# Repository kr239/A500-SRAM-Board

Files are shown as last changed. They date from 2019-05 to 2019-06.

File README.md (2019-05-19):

# A500-SRAM-Board

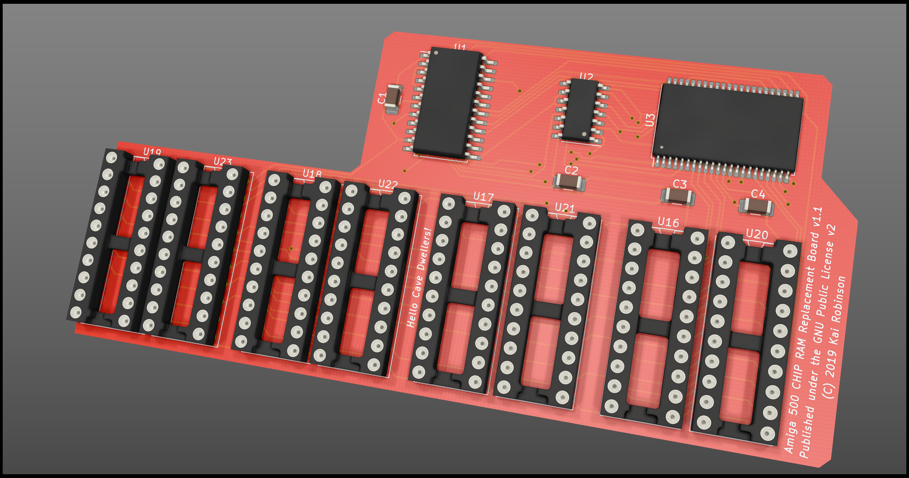
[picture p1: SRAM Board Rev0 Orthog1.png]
A500 SRAM Replacement Board


As with the previous DRAM board project, this will allow you to replace the old 44256 DRAM chips on your A500 with newer SRAM memory - a single 8Mbit chip, in fact. 

It's a lot simpler design, as there's just the single SRAM chip, a single 74ABT00 Quad NAND and a 74ABT821 10-bit D-Type Flip-Flop multiplexing the address lines.

The SRAM chip is a CY62157ESL-45ZSXI available from Mouser for less than £9 (at time of writing).

Ignore the image of the sockets, it's what KiCad generates as the 3D model.

Project is all done in KiCad 5.1.2

# Bill of Materials

4 x X7R 0.1uF MLCC SMD Capacitors (1206 (imperial))

1 x CY62157ESL-45ZSXI 8Mbit (512K x 16) SRAM (Cypress)

1 x SN74ABT821ADWR (SOIC-14) 10-bit D-Type Flip Flop (Texas Instruments)

1 x 74ABT00D-T Quad Input NAND Gate (Nexperia)

16 x 10-pin SIL Headers (Harwin M20-9991046)

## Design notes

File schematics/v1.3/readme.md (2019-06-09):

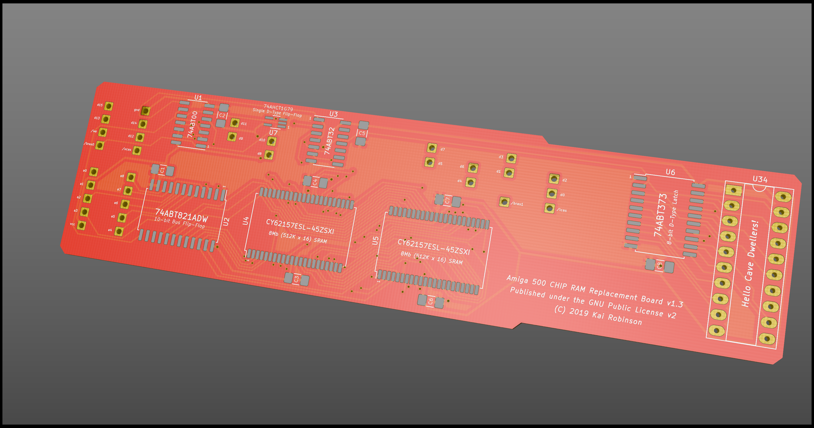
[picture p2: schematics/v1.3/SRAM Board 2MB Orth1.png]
2MB SRAM Board


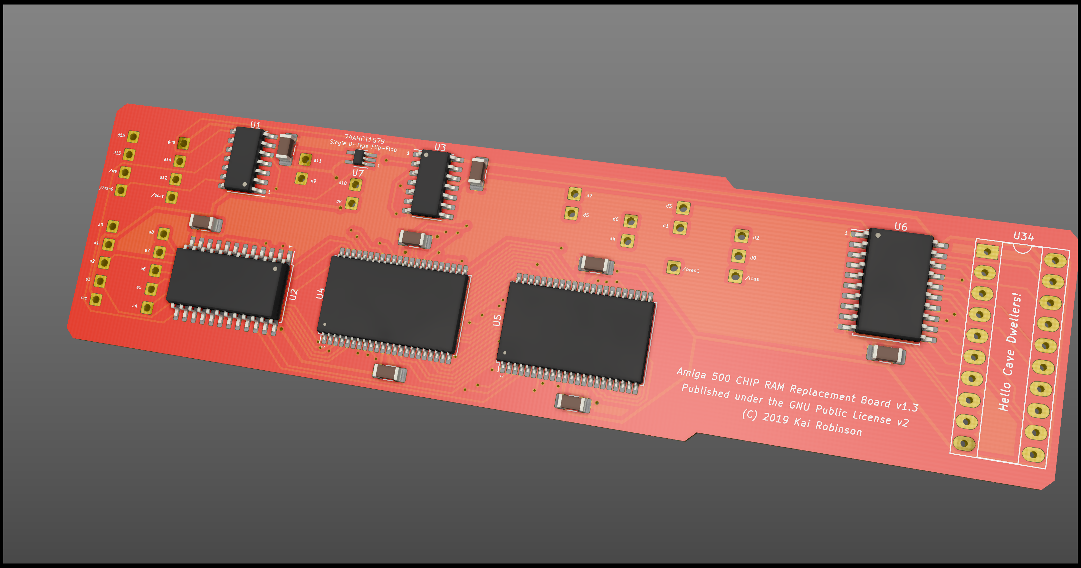
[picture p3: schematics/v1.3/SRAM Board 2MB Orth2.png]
2MB SRAM Board


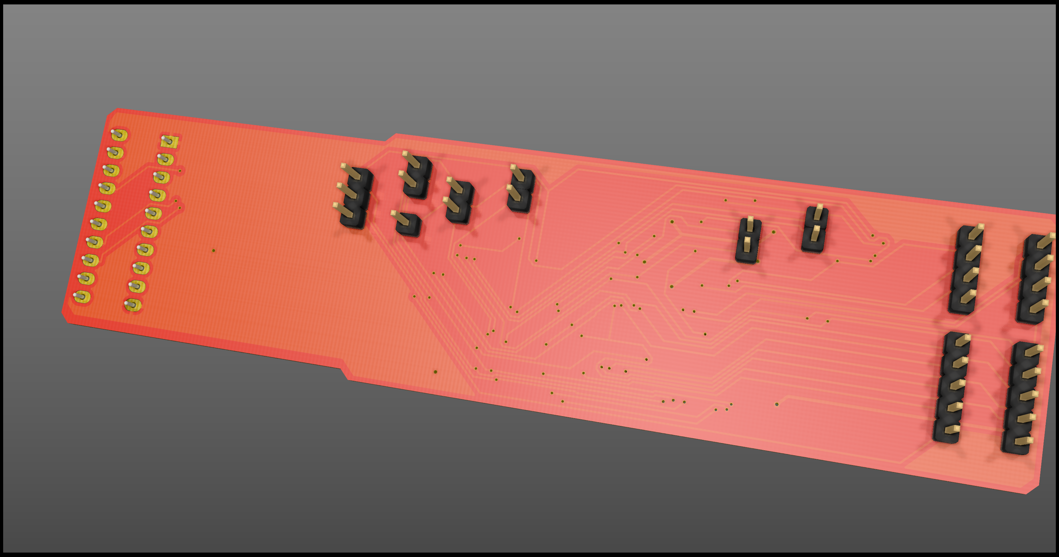
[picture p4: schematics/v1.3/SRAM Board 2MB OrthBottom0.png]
2MB SRAM Board 2MB SRAM Board Bottom


This is a significantly revised design based around two SRAM chips, using the buffered A9 input from U34 to provide sufficient address lines. This board will give 2MB CHIP RAM in an A500+ & the trapdoor expansion will be rendered useless for any memory expansions.

This board also has seen the design optimized significantly for low z-height, meaning it shouldn't foul the keyboard in a stock A500+ case. 

v1.3 also sees the introduction of an additional D-Type, Positive Edge triggered flip flop to feed A18 on the SRAM, rather than relying on /BRAS0 alone.

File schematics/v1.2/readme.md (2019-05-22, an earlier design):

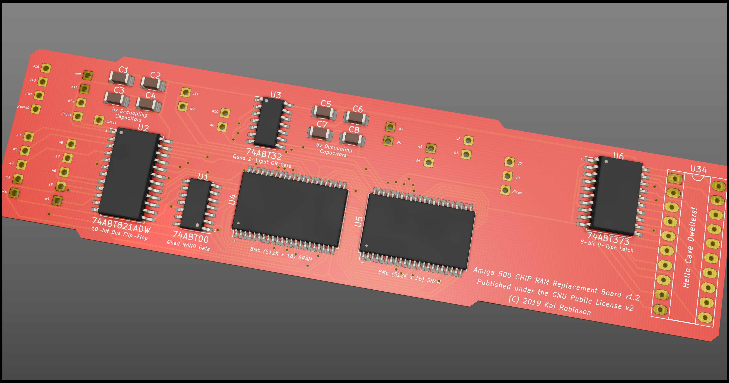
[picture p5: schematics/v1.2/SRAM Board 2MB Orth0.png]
2MB SRAM Board


This is a significantly revised design based around two SRAM chips, using the buffered A9 input from U34 to provide sufficient address lines. This board will give 2MB CHIP RAM in an A500+ & the trapdoor expansion will be rendered useless for any memory expansions.

This board also has seen the design optimized significantly for low z-height, meaning it shouldn't foul the keyboard in a stock A500+ case.

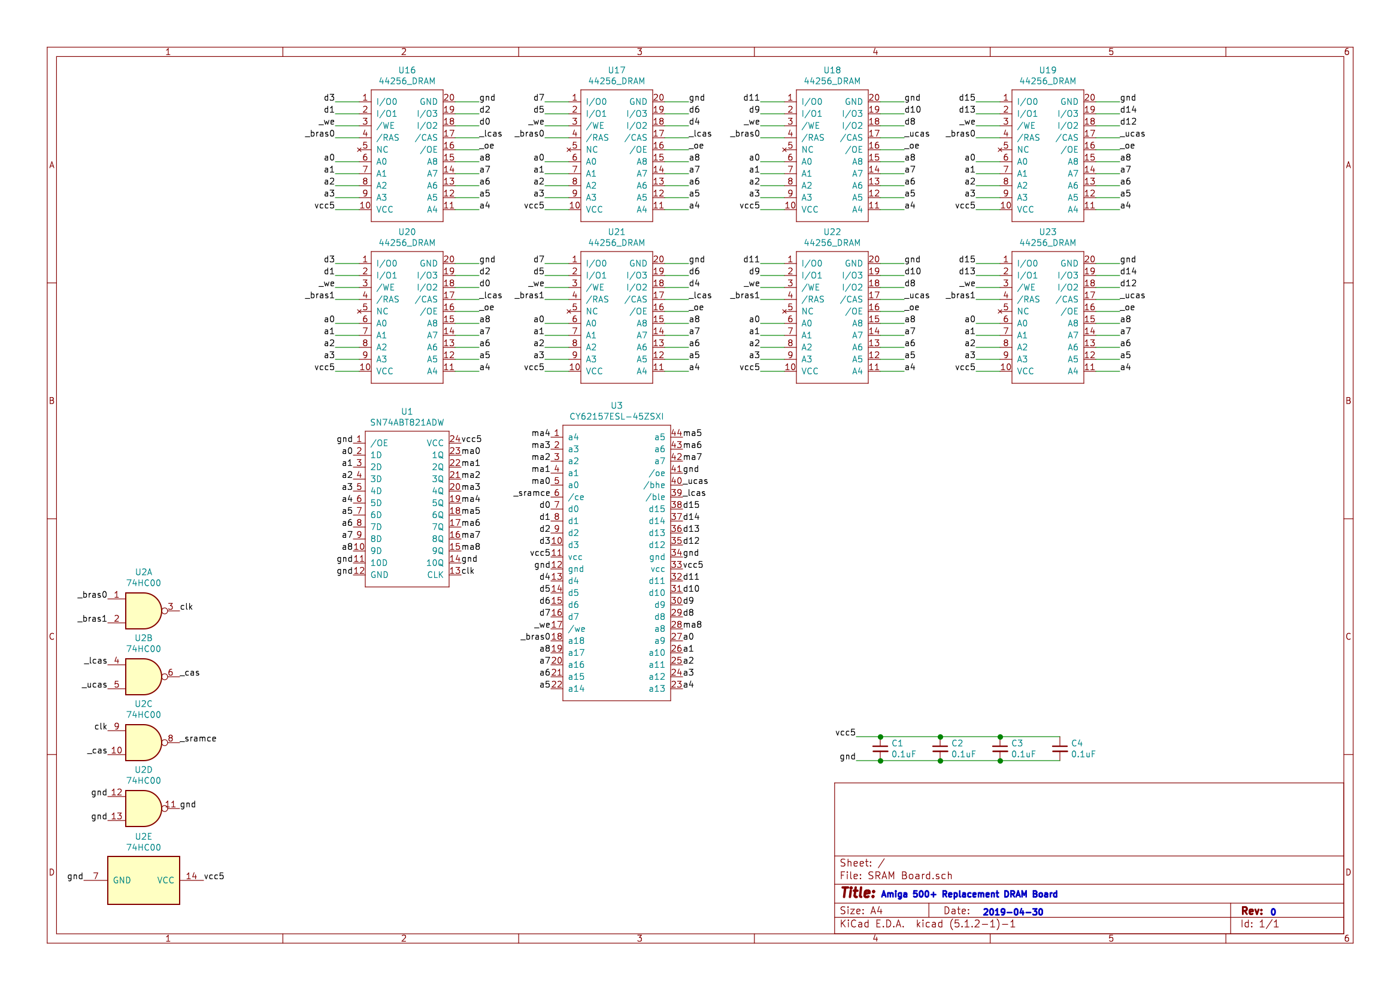
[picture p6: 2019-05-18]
schematics/SRAM Board Schematic.png

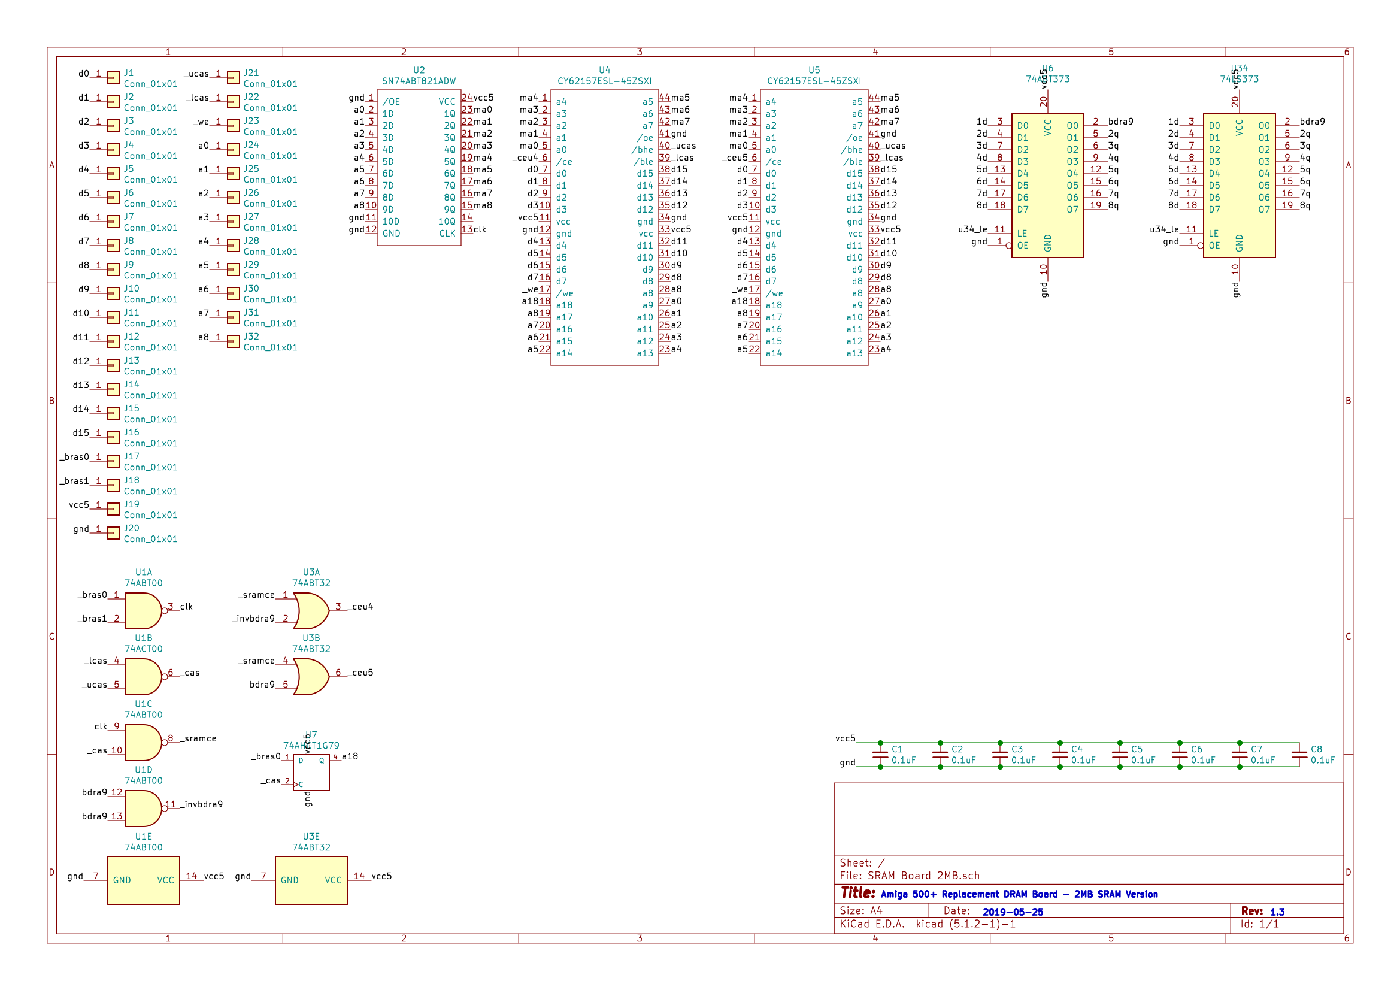
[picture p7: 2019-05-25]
schematics/v1.3/SRAM Board 2MB schematic.png

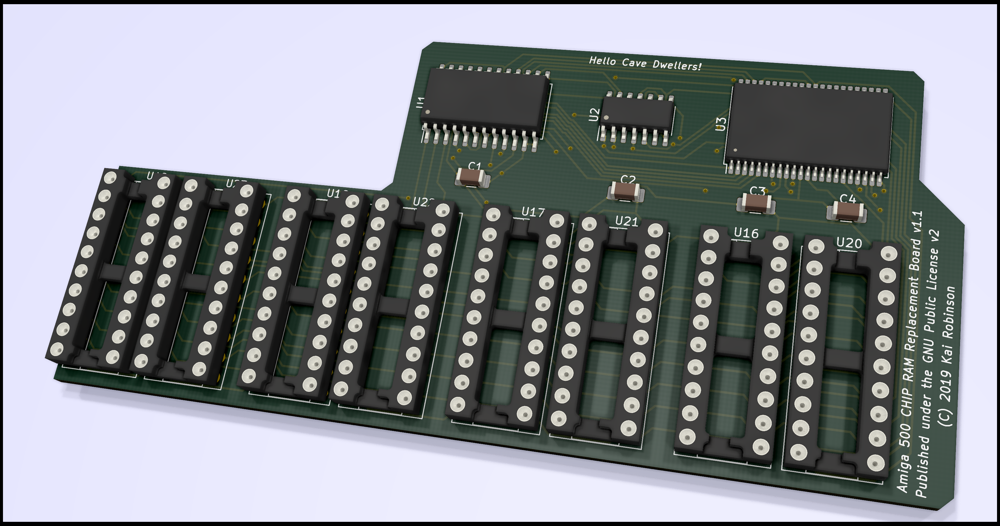
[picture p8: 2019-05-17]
SRAM Board Rev0 Orthog2.png

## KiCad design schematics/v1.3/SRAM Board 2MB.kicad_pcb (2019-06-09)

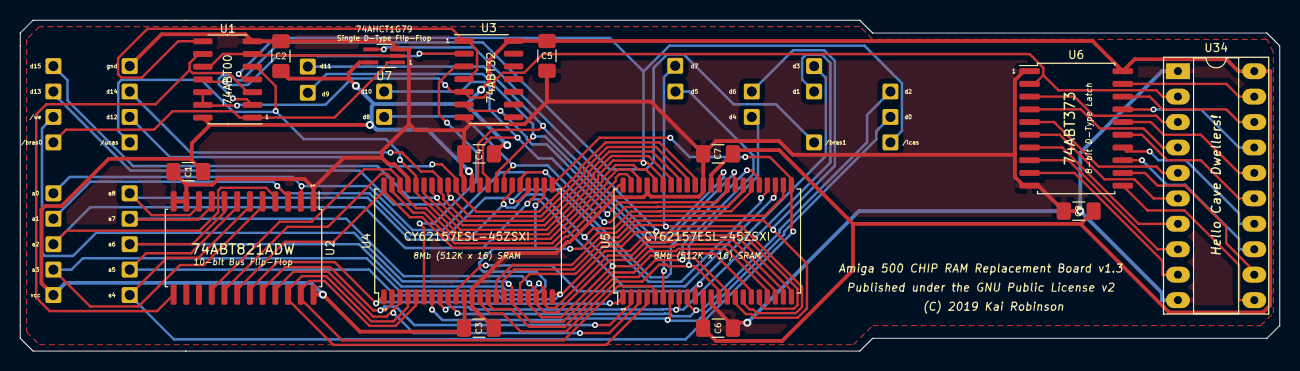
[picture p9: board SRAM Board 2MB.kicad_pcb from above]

Board: 2 copper layers, 125.7 x 33.0 mm, 48 parts (0 on the bottom side), 64 nets.

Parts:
C1, C2, C3, C4, C5, C6, C7, C8: 0.1uF; C_1206_3216Metric_Pad1.42x1.75mm_HandSolder
J1, J2, J3, J4, J5, J6, J7, J8, J9, J10, J11, J12, J13, J14, J15, J16, J17, J18, J19, J20, J21, J22, J23, J24, J25, J26, J27, J28, J29, J30, J31, J32: Conn_01x01; PinHeader_1x01_P2.54mm_Vertical
U1: 74ABT00; SOIC-14_3.9x8.7mm_P1.27mm
U2: 74ABT821ADW; SOIC-24W_7.5x15.4mm_P1.27mm
U3: 74ABT32; SOIC-14_3.9x8.7mm_P1.27mm
U4, U5: CY62157ESL-45ZSXI; TSOP-II-44_10.16x18.41mm_P0.8mm_copy
U6: 74ABT373; SOIC-20W_7.5x12.8mm_P1.27mm
U7: 74AHCT1G79; SOT-353_SC-70-5_Handsoldering
U34: 74LS373; DIP-20_W7.62mm_Socket_LongPads

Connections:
/1d: U6.3, U34.3
/2d: U6.4, U34.4
/2q: U6.5, U34.5
/3d: U6.7, U34.7
/3q: U6.6, U34.6
/4d: U6.8, U34.8
/4q: U6.9, U34.9
/5d: U6.13, U34.13
/5q: U6.12, U34.12
/6d: U6.14, U34.14
/6q: U6.15, U34.15
/7d: U6.17, U34.17
/7q: U6.16, U34.16
/8d: U6.18, U34.18
/8q: U6.19, U34.19
/_bras0: J17.1, U1.1, U7.1
/_bras1: J18.1, U1.2
/_cas: U1.6, U1.10, U7.2
/_ceu4: U3.3, U4.6
/_ceu5: U3.6, U5.6
/_invbdra9: U1.11, U3.2
/_lcas: J22.1, U1.4, U4.39, U5.39
/_sramce: U1.8, U3.1, U3.4
/_ucas: J21.1, U1.5, U4.40, U5.40
/_we: J23.1, U4.17, U5.17
/a0: J24.1, U2.2, U4.27, U5.27
/a1: J25.1, U2.3, U4.26, U5.26
/a2: J26.1, U2.4, U4.25, U5.25
/a3: J27.1, U2.5, U4.24, U5.24
/a4: J28.1, U2.6, U4.23, U5.23
/a5: J29.1, U2.7, U4.22, U5.22
/a6: J30.1, U2.8, U4.21, U5.21
/a7: J31.1, U2.9, U4.20, U5.20
/a8: J32.1, U2.10, U4.19, U4.28, U5.19, U5.28
/a18: U4.18, U5.18, U7.4
/bdra9: U1.12, U1.13, U3.5, U6.2, U34.2
/clk: U1.3, U1.9, U2.13
/d0: J1.1, U4.7, U5.7
/d1: J2.1, U4.8, U5.8
/d2: J3.1, U4.9, U5.9
/d3: J4.1, U4.10, U5.10
/d4: J5.1, U4.13, U5.13
/d5: J6.1, U4.14, U5.14
/d6: J7.1, U4.15, U5.15
/d7: J8.1, U4.16, U5.16
/d8: J9.1, U4.29, U5.29
/d9: J10.1, U4.30, U5.30
/d10: J11.1, U4.31, U5.31
/d11: J12.1, U4.32, U5.32
/d12: J13.1, U4.35, U5.35
/d13: J14.1, U4.36, U5.36
/d14: J15.1, U4.37, U5.37
/d15: J16.1, U4.38, U5.38
/ma0: U2.23, U4.5, U5.5
/ma1: U2.22, U4.4, U5.4
/ma2: U2.21, U4.3, U5.3
/ma3: U2.20, U4.2, U5.2
/ma4: U2.19, U4.1, U5.1
/ma5: U2.18, U4.44, U5.44
/ma6: U2.17, U4.43, U5.43
/ma7: U2.16, U4.42, U5.42
/u34_le: U6.11, U34.11
GND: C1.2, C2.2, C3.2, C4.2, C5.2, C6.2, C7.2, C8.2, J20.1, U1.7, U2.1, U2.11, U2.12, U3.7, U4.12, U4.34, U4.41, U5.12, U5.34, U5.41, U6.1, U6.10, U7.3, U34.1, U34.10
VCC: C1.1, C2.1, C3.1, C4.1, C5.1, C6.1, C7.1, C8.1, J19.1, U1.14, U2.24, U3.14, U4.11, U4.33, U5.11, U5.33, U6.20, U7.5, U34.20

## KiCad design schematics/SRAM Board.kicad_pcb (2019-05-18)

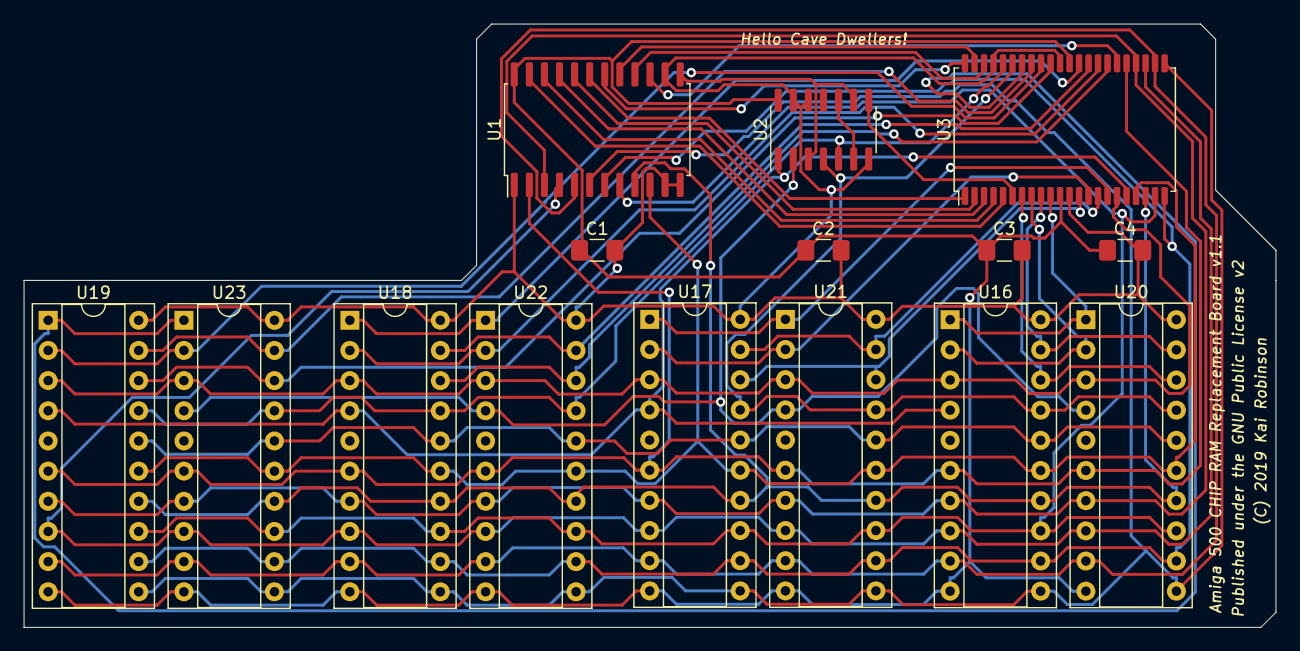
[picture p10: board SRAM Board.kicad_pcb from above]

Board: 2 copper layers, 105.4 x 50.8 mm, 15 parts (0 on the bottom side), 45 nets.

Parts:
C1, C2, C3, C4: 0.1uF; C_1206_3216Metric_Pad1.42x1.75mm_HandSolder
U1: SN74ABT821ADW; SOIC-24W_7.5x15.4mm_P1.27mm
U2: 74HC00; SOIC-14_3.9x8.7mm_P1.27mm
U3: CY62157ESL-45ZSXI; TSOP-II-44_10.16x18.41mm_P0.8mm_copy
U16, U17, U18, U19, U20, U21, U22, U23: 44256_DRAM; DIP-20_W7.62mm_Socket

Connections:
/_bras0: U2.1, U3.18, U16.4, U17.4, U18.4, U19.4
/_bras1: U2.2, U20.4, U21.4, U22.4, U23.4
/_cas: U2.6, U2.10
/_lcas: U2.4, U3.39, U16.17, U17.17, U20.17, U21.17
/_oe: U16.16, U17.16, U18.16, U19.16, U20.16, U21.16, U22.16, U23.16
/_sramce: U2.8, U3.6
/_ucas: U2.5, U3.40, U18.17, U19.17, U22.17, U23.17
/_we: U3.17, U16.3, U17.3, U18.3, U19.3, U20.3, U21.3, U22.3, U23.3
/a0: U1.2, U3.27, U16.6, U17.6, U18.6, U19.6, U20.6, U21.6, U22.6, U23.6
/a1: U1.3, U3.26, U16.7, U17.7, U18.7, U19.7, U20.7, U21.7, U22.7, U23.7
/a2: U1.4, U3.25, U16.8, U17.8, U18.8, U19.8, U20.8, U21.8, U22.8, U23.8
/a3: U1.5, U3.24, U16.9, U17.9, U18.9, U19.9, U20.9, U21.9, U22.9, U23.9
/a4: U1.6, U3.23, U16.11, U17.11, U18.11, U19.11, U20.11, U21.11, U22.11, U23.11
/a5: U1.7, U3.22, U16.12, U17.12, U18.12, U19.12, U20.12, U21.12, U22.12, U23.12
/a6: U1.8, U3.21, U16.13, U17.13, U18.13, U19.13, U20.13, U21.13, U22.13, U23.13
/a7: U1.9, U3.20, U16.14, U17.14, U18.14, U19.14, U20.14, U21.14, U22.14, U23.14
/a8: U1.10, U3.19, U16.15, U17.15, U18.15, U19.15, U20.15, U21.15, U22.15, U23.15
/clk: U1.13, U2.3, U2.9
/d0: U3.7, U16.18, U20.18
/d1: U3.8, U16.2, U20.2
/d2: U3.9, U16.19, U20.19
/d3: U3.10, U16.1, U20.1
/d4: U3.13, U17.18, U21.18
/d5: U3.14, U17.2, U21.2
/d6: U3.15, U17.19, U21.19
/d7: U3.16, U17.1, U21.1
/d8: U3.29, U18.18, U22.18
/d9: U3.30, U18.2, U22.2
/d10: U3.31, U18.19, U22.19
/d11: U3.32, U18.1, U22.1
/d12: U3.35, U19.18, U23.18
/d13: U3.36, U19.2, U23.2
/d14: U3.37, U19.19, U23.19
/d15: U3.38, U19.1, U23.1
/gnd: C1.2, C2.2, C3.2, C4.2, U1.1, U1.11, U1.12, U1.14, U2.7, U2.12, U2.13, U3.12, U3.34, U3.41, U16.20, U17.20, U18.20, U19.20, U20.20, U21.20, U22.20, U23.20
/ma0: U1.23, U3.5
/ma1: U1.22, U3.4
/ma2: U1.21, U3.3
/ma3: U1.20, U3.2
/ma4: U1.19, U3.1
/ma5: U1.18, U3.44
/ma6: U1.17, U3.43
/ma7: U1.16, U3.42
/ma8: U1.15, U3.28
/vcc5: C1.1, C2.1, C3.1, C4.1, U1.24, U2.14, U3.11, U3.33, U16.10, U17.10, U18.10, U19.10, U20.10, U21.10, U22.10, U23.10

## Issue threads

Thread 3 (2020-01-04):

U2E output shouldn't be connected to gnd

LIV2, 2020-01-04:
Inputs for the NAND gate are connected to GND so the gate will be driving Logic 1 on the output, however the output is connected to GND so it will be essentially shorting to ground, will draw more current

LIV2, 2020-01-04:
Nevermind, I see it must have been an older revision

Closed 2020-01-04.

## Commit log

2019-05-17 Add files via upload
    Fixing a glaring error - I had grounded A18, rather than assigning it to _bras0 instead.
    [SRAM Board.dsn, SRAM Board.kicad_pcb, SRAM Board.sch]
2019-05-17 Add files via upload
    Re-done due to A18 being grounded rather than being assigned to _bras0.
    [SRAM Board-B_Cu.gbl, SRAM Board-Edge_Cuts.gm1, SRAM Board-F_Cu.gtl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]
2019-05-18 Add files via upload
    Switching the 74ABT00 pin 11 from GND to NC
    [SRAM Board.dsn, SRAM Board.kicad_pcb, SRAM Board.sch]
2019-05-19 Add files via upload
    Bottom Solder Mask had been excluded in error
    [SRAM Board-B_Cu.gbl, SRAM Board-Edge_Cuts.gm1, SRAM Board-F_Cu.gtl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]
2019-05-20 Add files via upload
    Actually remembered the rear mask :D
    [SRAM Board-B_Cu.gbl, SRAM Board-B_Mask.gbs, SRAM Board-Edge_Cuts.gm1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]
2019-06-06 Changed back to 2 layer board
    Changed to 2 layer board, using thicker power traces and a copper fill on both sides for VCC and GND planes.
    [SRAM Board 2MB-B_Cu.gbl, SRAM Board 2MB-B_Mask.gbs, SRAM Board 2MB-Edge_Cuts.gm1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]
2019-06-06 Create SRAM Board 2MB Orth1.png
    Updated PNG
2019-06-09 New Board Layout
    [SRAM Board 2MB-B_Cu.gbl, SRAM Board 2MB-B_Mask.gbs, SRAM Board 2MB-Edge_Cuts.gm1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]

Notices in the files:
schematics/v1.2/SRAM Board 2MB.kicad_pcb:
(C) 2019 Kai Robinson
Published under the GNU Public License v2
